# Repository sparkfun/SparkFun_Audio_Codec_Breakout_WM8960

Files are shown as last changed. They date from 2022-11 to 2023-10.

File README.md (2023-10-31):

Stereo Audio Codec Breakout - WM8960
========================================

<table class="table table-hover table-striped table-bordered">
  <tr align="center">
   <td><a href="https://www.sparkfun.com/products/21250">SparkFun Audio Codec Breakout - WM8960</a></td>
   <td><a href="https://www.sparkfun.com/products/21772">SparkFun Audio Codec Breakout - WM8960 with Headers (Qwiic)</a></td>
  </tr>
  <tr align="center">
   <td><i>SparkFun Audio Codec Breakout - WM8960<br />[<a href="https://www.sparkfun.com/products/21250">BOB-21250</a>]</i></td>
   <td><i>SparkFun Audio Codec Breakout - WM8960 with Headers (Qwiic)<br />[<a href="https://www.sparkfun.com/products/21772">BOB-21772</a>]</i></td>
  </tr>
</table>

The SparkFun WM8960 Audio Codec Breakout is a low-power, high-quality stereo codec with 1W Stereo Class D speaker drivers and headphone drivers. The WM8960 acts as a stereo audio ADC and DAC and communicates using I<sup>2</sup>S, a standard audio data protocol (not to be confused with I<sup>2</sup>C). This audio codec is chock full of features some of which include advanced on-chip digital signal processing for automatic level control (ALC) for the line or microphone input, programmable gain amplifier (PGA), pop and click suppression, and its ability to configure I<sup>2</sup>S settings and analog audio path through software via I<sup>2</sup>C. 

The 6x flexible analog input pins allow for a variety of sound source signal types to be routed internally to the ADC inputs. These signal types include line level and microphone level (balanced, and un-balanced) sources. This allows you to accept audio from the sound card on your computer, headphone output of your smartphone, electret microphones, MEMs microphone, etc. The flexible analog signal routing includes PGAs and multiple boost stages so that it can accept a wide range of audio signal levels.

Its efficient class-D driver also means low heat and long battery life when driving 8&ohm; speakers at up to 1W per channel for portable audio applications. As an alternative output, users can also use the audio codec to drive 16&ohm; headphones at up to 40mW for portable audio applications.

Audio feeling a bit... empty? Turn on the 3D enhancement to artificially increase the separation between the left and right channels. In other words, you will feel as if the room is full of sound coming from all directions during playback.  We've written an extensive Arduino Library that allows you to easily control all of the audio codec's features from simple volume control to 3D-enhanced audio playback. 

The board breaks out the WM8960 pins along the edge of the PCB with 0.1"-spaced pins to connect to a breadboard. Utilizing our handy Qwiic system saves you from manually wiring the I<sup>2</sup>C port when configuring the audio codec's settings. A power LED (PWR) is included on the board to indicate when power is applied to the audio CODEC through 3.3V. It can be disabled by cutting the LED jumper on the bottom side. To power the analog (AVDD) and speaker driver (SPKVDD), you will need to include power on the VIN pin. The built-in XC6222 3.3V/700mA voltage regulator regulates the voltage down for the analog circuit. Jumpers for the analog circuit (i..e. AVDD-ISO) and speaker drivers (VIN/SPKVDD) are included for users that want to power each with a separate power supply. 

This board is great for projects that require you to encode or decode audio signals. Add the SparkFun Audio Codec Breakout WM8960 to your next portable digital player or immersive VR game. 

Repository Contents
-------------------

* **/Documents** - Datasheets, additional product information
* **/Hardware** - Eagle design files (.brd, .sch)

Documentation
--------------

* **[Library](https://github.com/sparkfun/SparkFun_WM8960_Arduino_Library)** - Arduino library for the Stereo Audio Codec Breakout - WM8960.
* **[SparkFun Fritzing Part](https://github.com/sparkfun/Fritzing_Parts/blob/main/products/21250_sfe_stereo_audio_codec_breakout_WM8960.fzpz)** - Fritzing diagrams for SparkFun products.
* **[Hookup Guide](https://learn.sparkfun.com/tutorials/2761)** - Basic hookup guide for the Stereo Audio Codec Breakout - WM8960.

Product Versions
----------------

* [BOB-21772](https://www.sparkfun.com/products/21772) - v1.0, with headers
* [BOB-21250](https://www.sparkfun.com/products/21250) - Initial Release, v1.0 

Version History
---------------
* v1.0 - Initial Release 

License Information
-------------------

This product is _**open source**_! 

Please review the LICENSE.md file for license information. 

If you have any questions or concerns on licensing, please contact technical support on our [SparkFun forums](https://forum.sparkfun.com/viewforum.php?f=152).

Distributed as-is; no warranty is given.

- Your friends at SparkFun.

_<COLLABORATION CREDIT>_

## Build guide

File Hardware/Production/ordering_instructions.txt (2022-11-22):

panel size, 91x178mm
PCB thickness, 1.6mm
number of layers, 4
soldermask color, Red
silkscreen color, White
oz copper, 1oz
finish, HASL lead free
stencils, top
pcs per panel, 12
min trace width, 0.2032mm / 0.0080in
min drill size, 0.3810mm / 0.0150in
filename to layer stackup 1/2/3/4: GTL, GL2, GL3, GBL

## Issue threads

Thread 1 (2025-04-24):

[Question] Accessing MICBIAS on WM8960 and Raspberry PI

AustinMutschler, 2025-04-24:
## Background

I have a question that is not directly about this audio hat but uses the same WM8960 audio chip and was wondering if any of you folks could point me in the right direction (I know this is not the best place but I don't know who else to ask). I'm using the [SparkFun Audio Codec Breakout - WM8960](https://learn.sparkfun.com/tutorials/audio-codec-breakout---wm8960-hookup-guide/all#introduction).

I have been searching everywhere online to make this board work with the PI as it is usually used with arduinos but I get stuck at powering the electret mic with micbias.

Currently the Waveshare WM8960 soundcard overlay is the only one I have found for this audio chip. I am not entirely sure if it is the MICBIAS control that is not working but after all the troubleshooting, it is the consistent thing that keeps coming back up as it never reads any voltage while recording. Speakers work great by the way.

## The Project

<details>
 <summary>Full Wiring Diagram</summary>

**Power**
Pi 3.3V (Physical Pin 1 or 17) -> WM8960 3V3
Pi 5V (Physical Pin 2 or 4) -> WM8960 VIN
Pi Ground (Any GND Pin, e.g., Pin 6) -> WM8960 GND

**I2C**
Pi SDA (GPIO 2, Physical Pin 3) -> WM8960 SDA
Pi SCL (GPIO 3, Physical Pin 5) -> WM8960 SCL

**I2S**
Pi BCLK (Bit Clock) (GPIO 18, Physical Pin 12) -> WM8960 BCLK
Pi LRC / WS (Left/Right Clock / Word Select) (GPIO 19, Physical Pin 35) -> WM8960 DACLRC (also referred to as DLRC on top silkscreen) - The datasheet notes this often serves as the frame clock for both ADC and DAC when the ADC is enabled.
Pi DOUT (Data Out from Pi / Data In to Codec) (GPIO 21, Physical Pin 40) -> WM8960 DACDAT (also referred to as DDAT on top silkscreen)
Pi DIN (Data In to Pi / Data Out from Codec) (GPIO 20, Physical Pin 38) -> WM8960 ADCDAT (also referred to as ADAT on top silkscreen)

**MIC**
MICBIAS -> 2.2kohm resistor -> LINPUT2
MIC+ -> LINPUT2
MIC- -> LINPUT1
LINPUT1 -> JUMPER -> GND

</details>

I am attempting to connect this board to a Raspberry PI 4. It currently runs the latest version of Raspberry PI OS and by default the wb8960-soundcard overlay is [this one](https://github.com/raspberrypi/linux/blob/rpi-6.12.y/arch/arm/boot/dts/overlays/wm8960-soundcard-overlay.dts).

I am connecting an analog speaker and what I believe is a Electret Microphone from this [ATT 210 phone](https://a.co/d/7MxzDRN). The basic idea is, I am taking over the phone's matrix keypad with the PI and it's audio, not using any of the board in the phone whatsoever besides the matrix keypad. I have already setup the keypad matrix to the PI GPIO but then I needed audio. This phone is small so I cannot use a hat for the project. In fact, I purchased this audio hat first. The second issue I had was I wanted to use the original phone microphone because it will likely be better than a MEMS mic sitting in the housing. I found that the SparkFun WM8960 Board checked all the boxes as it supports external electret mics.

I setup the speaker and it worked after turning on the "Left Out Mixer PCM" setting.

Then I turned to the microphone...

## The Mic Setup

I set the microphone up in a [differential configuration](https://learn.sparkfun.com/tutorials/audio-codec-breakout---wm8960-hookup-guide/all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,Differential%20Microphone%20Input,-The%20following%20connection). This means I connected it in the following way:

MICBIAS -> 2.2kohm resistor -> LINPUT2
MIC+ -> LINPUT2
MIC- -> LINPUT1
LINPUT1 -> JUMPER -> GND

Previously I did try to do a standard mic setup but it yielded the same results:
MICBIAS -> 2.2kohm resistor -> LINPUT1
MIC+ -> LINPUT1
MIC- -> GND

The Card is 3 so for code examples below I have listed 3,0 which is targeting the WM8960.

<details>
 <summary>Full alsamixer Settings</summary>

```text
headphone - off (I have tried this setting on and off)
headphone playback zc - off
speaker - db gain: -17 -17
speaker ac - 0
speaker dc - 0
speaker playback zc - off
PCM Playback - 00 (enabled)
Mono Output Mixer Left - off
Mono Output Mixer Right - off
Playback - DB -20 -20
capture volume zc - off - (NOTE: I have had this off and on and neither make a difference)
3d - mute
3d filter lower cut-off - low
3d filter upper cut-off - high
ADC data - left data = left adc; right data = right adc
ADC high pass filter - off
ADC polarity - no inversion
ALC attack - 13
ALC Decay - 20
ALC Function - off
ALC Hold time - 0
ALC Max Gain - 100
ALC Min Gain - 0
ALC Mode - ALC
DAC Deemphasis - off
DAC Filter Characteristics - Normal
DAC Mono Mix - mono
DAC Polarity - No Inversion
Left Boost Mixer LINPUT1 - 00 (Enabled)
Left Boost Mixer LINPUT2 - Off (I have )
Left Boost Mixer LINPUT3- Off
Left Input Boost Mixer LINPUT1 - DB Gain 29 - 100%
Left Input Boost Mixer LINPUT2 - DB Gain 29 - 100%
Left Input Boost Mixer LINPUT3 - DB Gain mute - 0%
Left Input Mixer Boost - 00 (ENABLED)
Left Output Mixer Boost Bypass - db gain -15
Left Output Mixer LINPUT3 - db gain -15
Left Out Mixer PCM - 00 (ENABLED)
Noise Gate - off
Noise Gate Threshold - 0
Right Boost Mixer RINPUT1 - off
Right Boost Mixer RINPUT2 - off
Right Boost Mixer RINPUT3 - off
Right Input Boost Mixer RINPUT1 - DB Gain - 0%
Right Input Boost Mixer RINPUT2 - DB Gain mute - 0%
Right Input Boost Mixer RINPUT3 - DB Gain mute - 0%
Right Input Mixer Boost - off
Right Output Mixer Boost Bypass - DB Gain -15
Right Output Mixer PCM - off
Right Output Mixer RINPUT3 - DB Gain -15
```

</details>

<details>
 <summary>/boot/firmware/config.txt</summary>

```text
# For more options and information see
# http://rptl.io/configtxt
# Some settings may impact device functionality. See link above for details
dtdebug=1
# Uncomment some or all of these to enable the optional hardware interfaces
dtparam=i2c_arm=on
dtparam=i2s=on
#dtparam=spi=on

# Enable audio (loads snd_bcm2835)
dtparam=audio=on

# Additional overlays and parameters are documented
# /boot/firmware/overlays/README

# Automatically load overlays for detected cameras
camera_auto_detect=1

# Automatically load overlays for detected DSI displays
display_auto_detect=1

# Automatically load initramfs files, if found
auto_initramfs=1

# Enable DRM VC4 V3D driver
dtoverlay=vc4-kms-v3d
max_framebuffers=2

# Don't have the firmware create an initial video= setting in cmdline.txt.
# Use the kernel's default instead.
disable_fw_kms_setup=1

# Run in 64-bit mode
arm_64bit=1

# Disable compensation for displays with overscan
disable_overscan=1

# Run as fast as firmware / board allows
arm_boost=1

[cm4]
# Enable host mode on the 2711 built-in XHCI USB controller.
# This line should be removed if the legacy DWC2 controller is required
# (e.g. for USB device mode) or if USB support is not required.
otg_mode=1

[cm5]
dtoverlay=dwc2,dr_mode=host

[all]
dtoverlay=wm8960-soundcard
```

</details>

## The Problem

When trying to record audio, the audio file is completely silent. I have used the following commands to record and then test the file.

Note: I have also attempted to listen to the file and it is silent. I have also attempted to pipe the recording into the speaker and can confirm, I hear nothing.

```sh
arecord -D plughw:3,0 -f S16_LE -r 44100 -c 1 -d 10 test-mic.wav
sox test-mic.wav -n stat
```

Levels Remain at 0
```sh
arecord -D plughw:3,0 -f S16_LE -r 44100 -c1 -V mono /dev/null
```

### Suspected Issue

After a lot of trial and error, I believe the issue boils down to the MICBIAS **not** supplying voltage to the microphone. I have tested with my multimeter and it never seems to activate while recording on the device. I am not sure **why** voltage is not being supplied when recording, whether it is a setting I missed or if it is because the dtoverlay does not set MICBIAS

When running `dmesg | grep -i wm8960` I get the following messages

```sh
[    7.450473] wm8960 1-001a: supply DCVDD not found, using dummy regulator
[    7.450704] wm8960 1-001a: supply DBVDD not found, using dummy regulator
[    7.450891] wm8960 1-001a: supply SPKVDD1 not found, using dummy regulator
[    7.450949] wm8960 1-001a: supply SPKVDD2 not found, using dummy regulator
```

I am not sure if this is relevant or not to my issue.

### What Have I Tried

I have tried changing the audio capture controls around a lot and none seem to make the MIC work. I began looking into the [built in dtoverlay](https://github.com/raspberrypi/linux/blob/rpi-6.12.y/arch/arm/boot/dts/overlays/wm8960-soundcard-overlay.dts). I don't know much about overlays but noticed the official one bundled with the OS is for this this audio hat specifically and may hold the key to my issue.

I attempted to modify the dtoverlay to add some things that I might need. Granted, my knowledge is extremely limited with this and likely not correct. Here are the changes I made.

Within fragment@2 I added `micbias-supply` and `micbias-resistor` like so:

```text
fragment@2 {
		target = <&i2c1>;
		__overlay__ {
			#address-cells = <1>;
			#size-cells = <0>;
			status = "okay";

			wm8960: wm8960@1a {
				compatible = "wlf,wm8960";
				reg = <0x1a>;
				#sound-dai-cells = <0>;
				AVDD-supply = <&vdd_5v0_reg>;
				DVDD-supply = <&vdd_3v3_reg>;
				clocks = <&wm8960_mclk>;
				clock-names = "mclk";
				micbias-supply   = <&vdd_3v3_reg>;
				micbias-resistor = <2200>;
			};
		};
	};
```

Within fragment@3 I added the LINPUT2 to the simple-audio-card,routing section like so:

``` text
simple-audio-card,routing =
  "Headphone Jack", "HP_L",
  "Headphone Jack", "HP_R",
  "Speaker", "SPK_LP",
  "Speaker", "SPK_LN",
  "LINPUT1", "Mic Jack",
  "LINPUT2", "Mic Jack",
  "LINPUT3", "Mic Jack",
  "RINPUT1", "Mic Jack",
  "RINPUT2", "Mic Jack";
```

For compiling I used the following commands for all of my attempts

```shell
sudo dtc -@ -I dts -O dtb -o wm8960-soundcard-bias.dtbo wm8960-soundcard-bias-overlay.dts
sudo cp wm8960-soundcard-bias.dtbo /boot/firmware/overlays/
```
Then updated the config.txt file to match the correct name of the new dtoverlay `dtoverlay=wm8960-soundcard-bias` and rebooted.

To test that the audio card actually applied these settings to the device tree I ran the following commands:

```shell
sudo dtc -I fs -O dts /proc/device-tree > /tmp/flat.dts
grep -R "micbias" -n /tmp/flat.dts
```

Which yielded this result

```shell
253:				micbias-resistor = <0x898>;
261:				micbias-supply = <0xef>;
```

## Conclusion

I have tried rewiring the audio a few times to ensure it wasn't an issue with the wiring. I have checked that nothing is shorted on the hardware side and I2C is communicating. I have check voltages and everything is good except the MICBIAS pin. The speakers work.

I am not sure where to go from here. I assume that this audio hat does not require MICBIAS because of the built in MEMS microphone and therefore the controls are not in the dtoverlay. I do not know enough about dtoverlays to make the necessary modifications to port to the SparkFun WM8960 Breakout Board.

If anyone could point me in the right direction I would truly appreciate it.

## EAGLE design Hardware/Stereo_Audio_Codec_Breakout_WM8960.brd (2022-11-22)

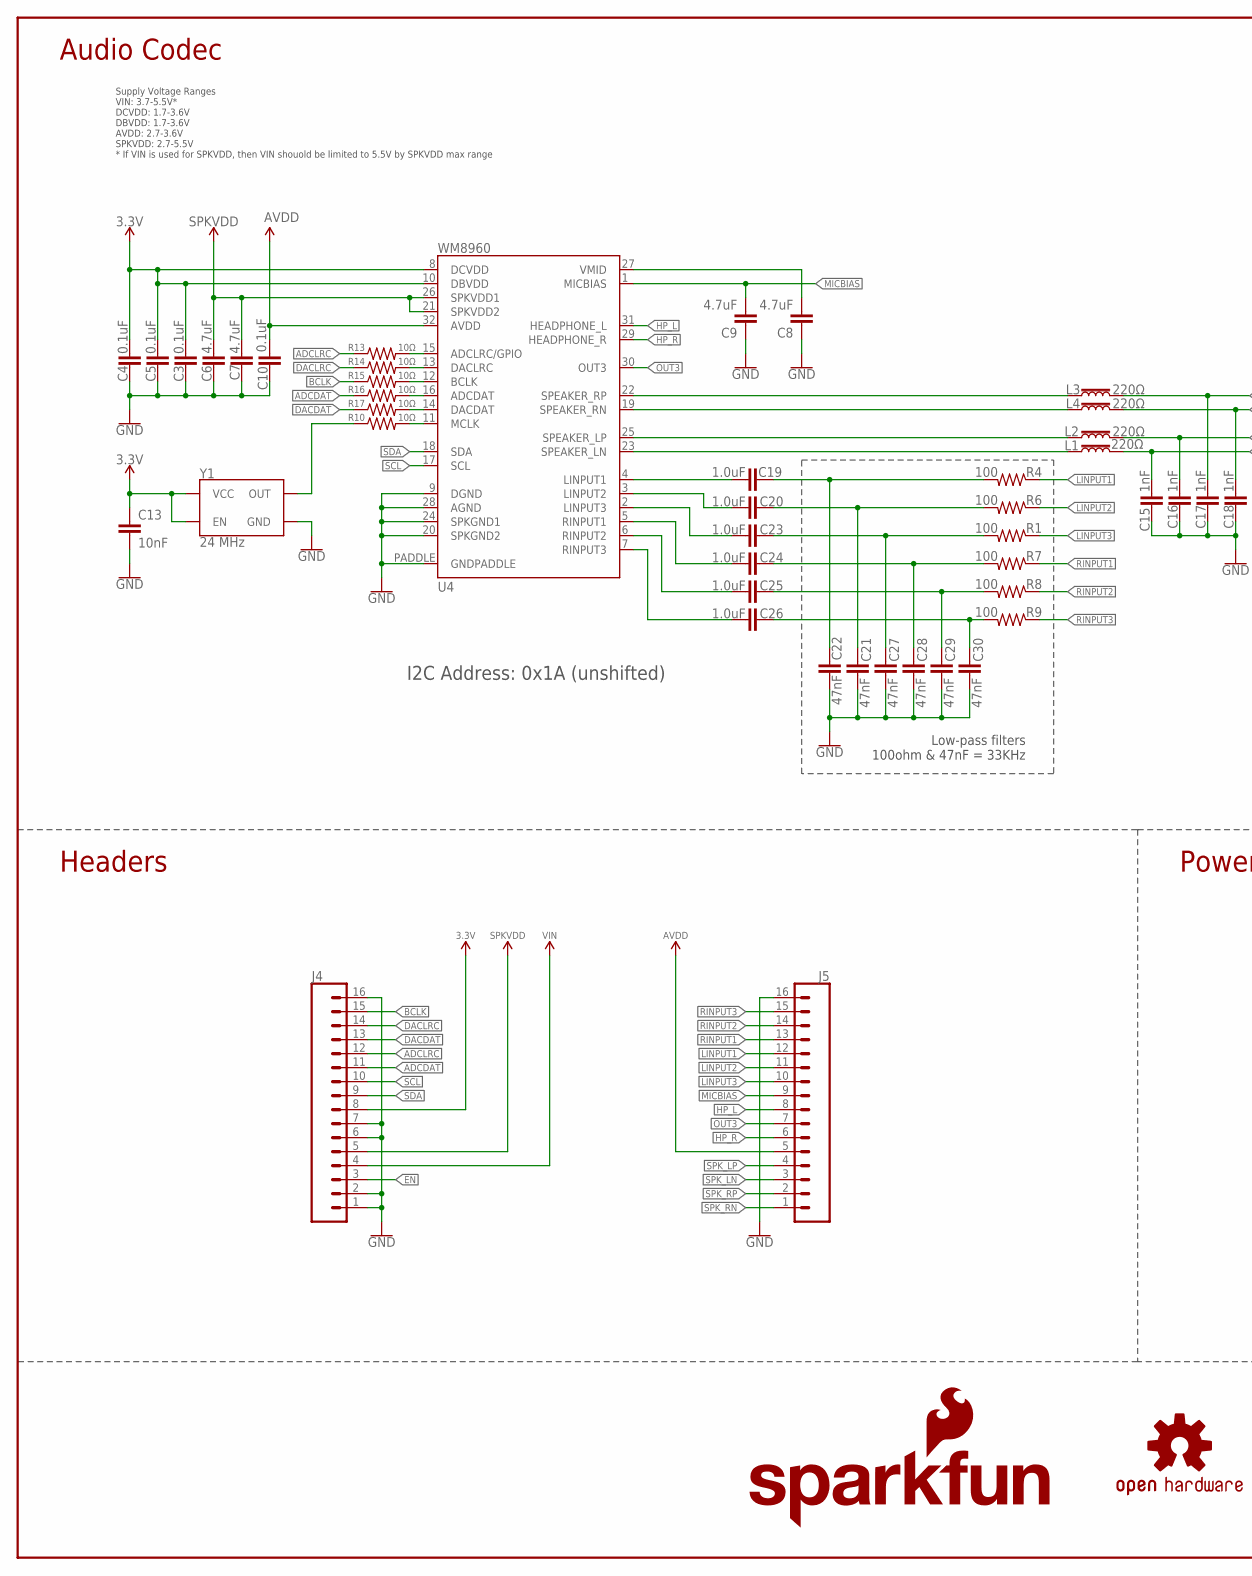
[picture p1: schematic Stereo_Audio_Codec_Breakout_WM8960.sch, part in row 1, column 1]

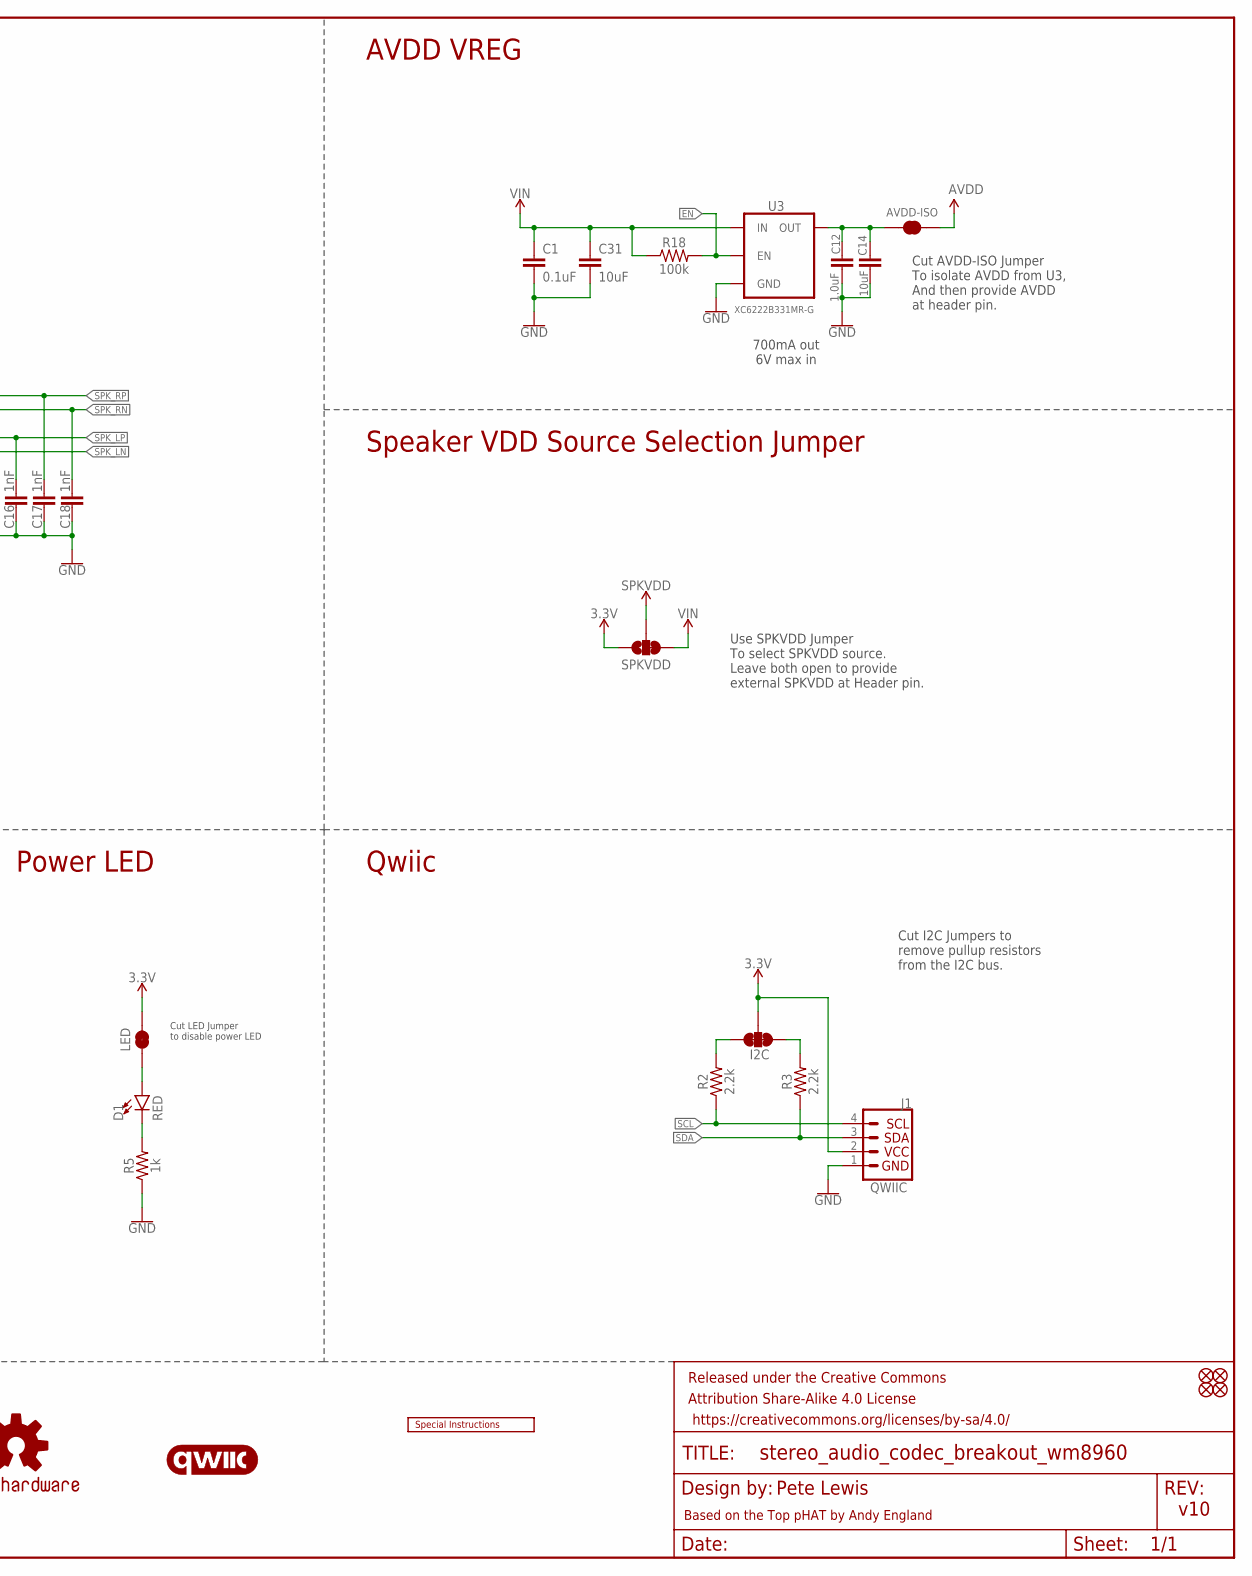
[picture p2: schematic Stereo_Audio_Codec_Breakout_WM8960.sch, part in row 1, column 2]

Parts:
AVDD-ISO: JUMPER-SMT_2_NC_TRACE_SILK; SMT-JUMPER_2_NC_TRACE_SILK
C1, C3, C4, C5, C10: 0.1uF; 0402-TIGHT
C6, C7: 4.7uF; 0603
C8, C9: 4.7uF; 0402-TIGHT
C12, C19, C20, C23, C24, C25, C26: 1.0uF; 0402-TIGHT
C13: 10nF; 0402-TIGHT
C14, C31: 10uF; 0402-TIGHT
C15, C16, C17, C18: 1nF; 0402
C21, C22, C27, C28, C29, C30: 47nF; 0402-TIGHT
D1: RED; LED-0603
FD1, FD2, FD3, FD4: FIDUCIALUFIDUCIAL; FIDUCIAL-MICRO
FRAME1: FRAME-LEDGER; CREATIVE_COMMONS
I2C: JUMPER-SMT_3_2-NC_TRACE_SILK; SMT-JUMPER_3_2-NC_TRACE_SILK
J1: QWIIC; JST04_1MM_RA
J4, J5: CONN_161X16_NO_SILK; 1X16_NO_SILK
L1, L2, L3, L4: 220Ω; 0805
LED: JUMPER-SMT_2_NC_TRACE_SILK; SMT-JUMPER_2_NC_TRACE_SILK
LOGO1: SFE_LOGO_NAME_FLAME.1_INCH; SFE_LOGO_NAME_FLAME_.1
LOGO3: QWIIC_LOGO_4MM; QWIIC_4MM
LOGO4: OSHW-LOGOS; OSHW-LOGO-S
LOGO5: SPECIAL_INSTRUCTIONS-ORDERING; ORDERING_INSTRUCTIONS
R1, R4, R6, R7, R8, R9: 100; 0402-TIGHT
R2, R3: 2.2k; 0402-TIGHT
R5: 1k; 0402-TIGHT
R10, R13, R14, R15, R16, R17: 10Ω; 0402-TIGHT
R18: 100k; 0402-TIGHT
SPKVDD: JUMPER-SMT_3_1-NC_TRACE_SILK; SMT-JUMPER_3_1-NC_TRACE_SILK
U3: XC6222B331MR-G; SOT23-5
U4: WM8960; QFN-32
Y1: 24 MHz; RESONATOR-SMD-3.2X2.5

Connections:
3.3V: C3.2, C4.2, C5.2, C13.1, I2C.2, J1.2, J4.8, LED.2, SPKVDD.1, U4.8 (DCVDD), U4.10 (DBVDD), Y1.1 (EN), Y1.4 (VCC)
ADCDAT: J4.11, R16.1
ADCLRC: J4.12, R13.1
AVDD: AVDD-ISO.2, C10.2, J5.5, U4.32 (AVDD)
AVDD-REG: AVDD-ISO.1, C12.1, C14.1, U3.5 (OUT)
BCLK: J4.15, R15.1
DACDAT: J4.13, R17.1
DACLRC: J4.14, R14.1
EN: J4.3, R18.2, U3.3 (EN)
GND: C1.2, C3.1, C4.1, C5.1, C6.2, C7.2, C8.1, C9.1, C10.1, C12.2, C13.2, C14.2, C15.2, C16.2, C17.2, C18.2, C21.2, C22.2, C27.2, C28.2, C29.2, C30.2, C31.2, J1.1, J4.1, J4.2, J4.6, J4.7, J4.16, J5.16, R5.1, U3.2 (GND), U4.9 (DGND), U4.20 (SPKGND2), U4.24 (SPKGND1), U4.28 (AGND), U4.PADDLE (GNDPADDLE), Y1.2 (GND)
HP_L: J5.8, U4.31 (HEADPHONE_L)
HP_R: J5.6, U4.29 (HEADPHONE_R)
LINPUT1: J5.12, R4.1
LINPUT2: J5.11, R6.1
LINPUT3: J5.10, R1.1
MICBIAS: C9.2, J5.9, U4.1 (MICBIAS)
unnamed: L3.1, U4.22 (SPEAKER_RP)
unnamed: R13.2, U4.15 (ADCLRC/GPIO)
unnamed: L4.1, U4.19 (SPEAKER_RN)
unnamed: L2.1, U4.25 (SPEAKER_LP)
unnamed: L1.1, U4.23 (SPEAKER_LN)
unnamed: D1.C, R5.2
unnamed: D1.A, LED.1
unnamed: C26.2, U4.7 (RINPUT3)
unnamed: C25.2, U4.6 (RINPUT2)
unnamed: C23.2, U4.2 (LINPUT3)
unnamed: R10.1, Y1.3 (OUT)
unnamed: C20.2, U4.3 (LINPUT2)
unnamed: C20.1, C21.1, R6.2
unnamed: C19.1, C22.1, R4.2
unnamed: C23.1, C27.1, R1.2
unnamed: I2C.3, R2.2
unnamed: I2C.1, R3.2
unnamed: C24.1, C28.1, R7.2
unnamed: C25.1, C29.1, R8.2
unnamed: C26.1, C30.1, R9.2
unnamed: R14.2, U4.13 (DACLRC)
unnamed: R15.2, U4.12 (BCLK)
unnamed: R16.2, U4.16 (ADCDAT)
unnamed: R17.2, U4.14 (DACDAT)
unnamed: R10.2, U4.11 (MCLK)
unnamed: C19.2, U4.4 (LINPUT1)
unnamed: C24.2, U4.5 (RINPUT1)
unnamed: C8.2, U4.27 (VMID)
OUT3: J5.7, U4.30 (OUT3)
RINPUT1: J5.13, R7.1
RINPUT2: J5.14, R8.1
RINPUT3: J5.15, R9.1
SCL: J1.4, J4.10, R2.1, U4.17 (SCL)
SDA: J1.3, J4.9, R3.1, U4.18 (SDA)
SPKVDD: C6.1, C7.1, J4.5, SPKVDD.2, U4.21 (SPKVDD2), U4.26 (SPKVDD1)
SPK_LN: C15.1, J5.3, L1.2
SPK_LP: C16.1, J5.4, L2.2
SPK_RN: C18.1, J5.1, L4.2
SPK_RP: C17.1, J5.2, L3.2
VIN: C1.1, C31.1, J4.4, R18.1, SPKVDD.3, U3.1 (IN)

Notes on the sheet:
Pete Lewis
Audio Codec
Cut I2C Jumpers to remove pullup resistors from the I2C bus.
v10
Based on the Top pHAT by Andy England
I2C Address: 0x1A (unshifted)
Cut LED Jumper to disable power LED
Low-pass filters 100ohm & 47nF = 33KHz
Supply Voltage Ranges VIN: 3.7-5.5V* DCVDD: 1.7-3.6V DBVDD: 1.7-3.6V AVDD: 2.7-3.6V SPKVDD: 2.7-5.5V * If VIN is used for SPKVDD, then VIN shouold be limited to 5.5V by SPKVDD max range
AVDD VREG
Headers
Qwiic
Speaker VDD Source Selection Jumper
700mA out 6V max in
Cut AVDD-ISO Jumper To isolate AVDD from U3, And then provide AVDD at header pin.
Use SPKVDD Jumper To select SPKVDD source. Leave both open to provide external SPKVDD at Header pin.
Power LED

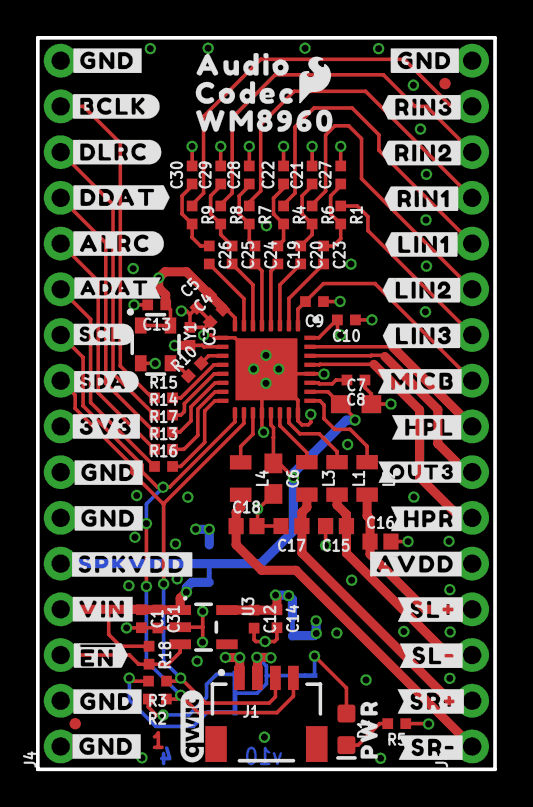
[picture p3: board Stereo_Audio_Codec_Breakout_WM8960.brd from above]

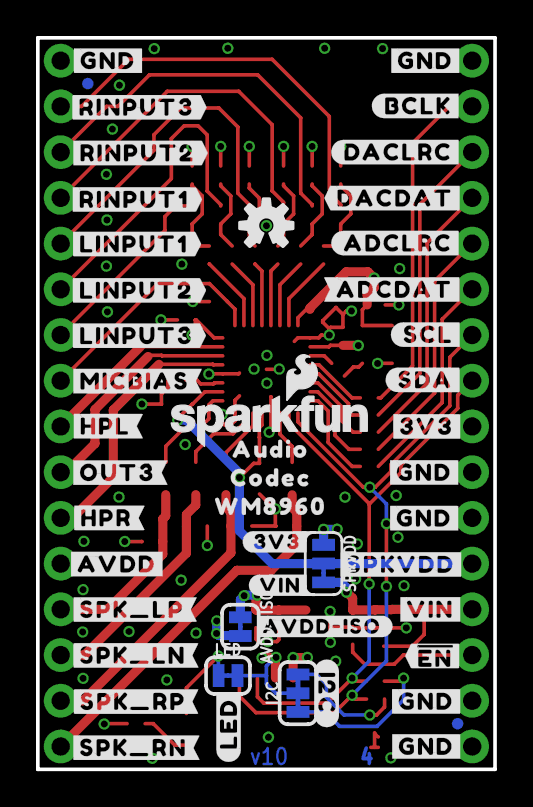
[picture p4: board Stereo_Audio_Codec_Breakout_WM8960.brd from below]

Board: 4 copper layers, 25.4 x 40.6 mm, 146 parts (48 on the bottom side), 56 nets.

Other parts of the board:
U$1: AUDIO8960896055
U$2: CODEC8960896056
U$3: CODEC8960896057
U$4, U$7, U$8, U$9, U$11, U$12, U$17, U$18, U$19, U$31, U$32, U$50: #GND#8
U$5: #BCLK#0
U$10, U$48: #AVDD#22
U$13: #SR##4
U$14: #SL##6
U$15: #SR##5
U$16: #SL##7
U$20: #AVDD#ISO#0
U$21: #3V3#0
U$22: #VIN#0
U$23: #ALRC#0
U$24: #DLRC#1
U$26: #HPL#10
U$27: #HPR#11
U$28, U$51: #3V3#12
U$29: SFE_LOGO_FLAME_.1
U$30, U$64: #SPKVDD#51
U$34: ##EN##1
U$35: PWR12
U$36: WM8960896054
U$37: #OUT3#0
U$38: ##EN##2
U$39: #LED#17
U$40: #I2C#18
U$41: #OUT3#4
U$44: #RINPUT1#0
U$45, U$46: #VIN#19
U$47: #RINPUT2#0
U$49: #RINPUT3#0
U$52: #ADCLRC#2
U$54: #RIN3#0
U$55: #DACLRC#4
U$56: #RIN2#0
U$57: #BCLK#5
U$58: #ADCDAT#6
U$59: #MICB#31
U$60: WM89600
U$61: AUDIO0
U$62: #LINPUT1#0
U$63: #LINPUT2#0
U$65: #LINPUT3#0
U$66: #SCL#0
U$67: #SDA#0
U$68: #RIN1#0
U$69: #DDAT#9
U$70: #DACDAT#8
U$71: #ADAT#10
U$74: #SCL#40
U$75: #SDA#41
U$76: #LIN1#0
U$77: #LIN2#0
U$78: #LIN3#0
U$79: #MICBIAS#42
U$80: #HPL#43
U$82: #HPR#45
U$83: #SPK_LP#46
U$84: #SPK_LN#47
U$85: #SPK_RP#48
U$86: #SPK_RN#49

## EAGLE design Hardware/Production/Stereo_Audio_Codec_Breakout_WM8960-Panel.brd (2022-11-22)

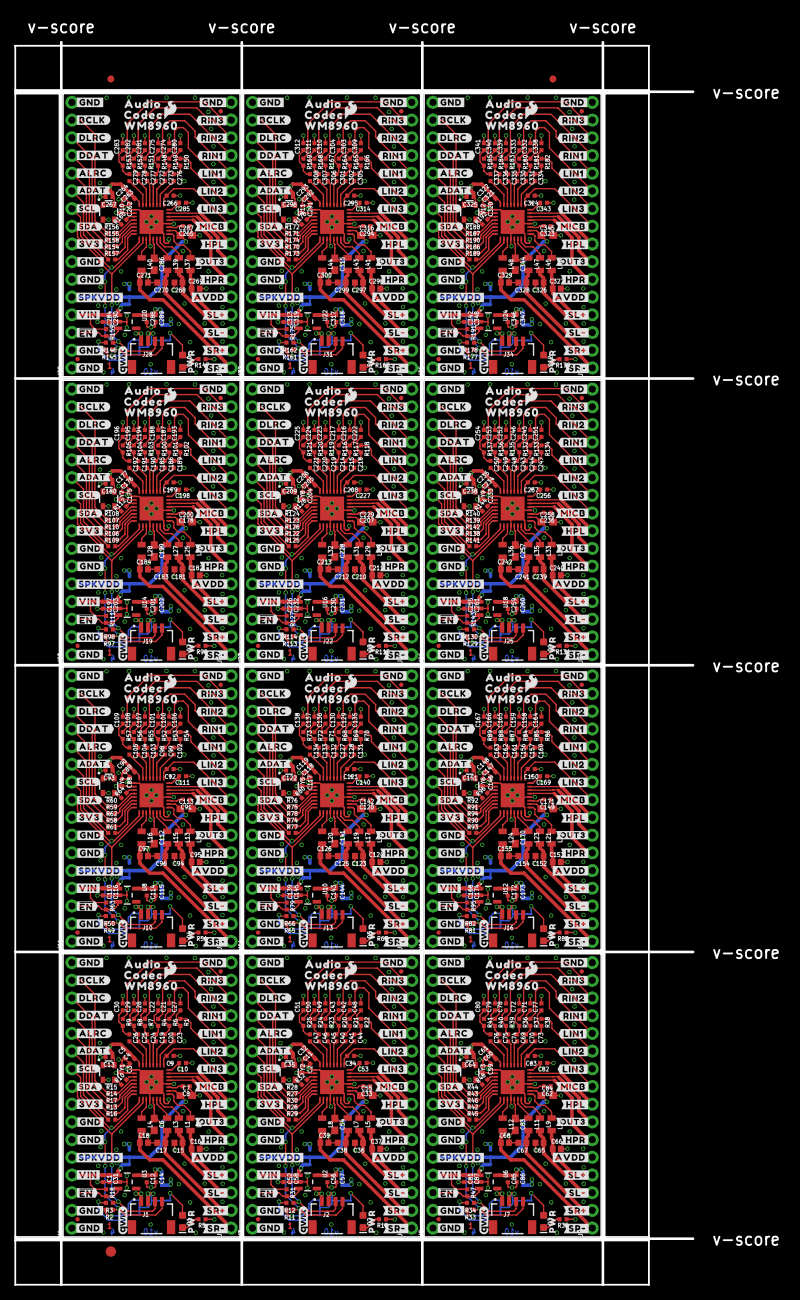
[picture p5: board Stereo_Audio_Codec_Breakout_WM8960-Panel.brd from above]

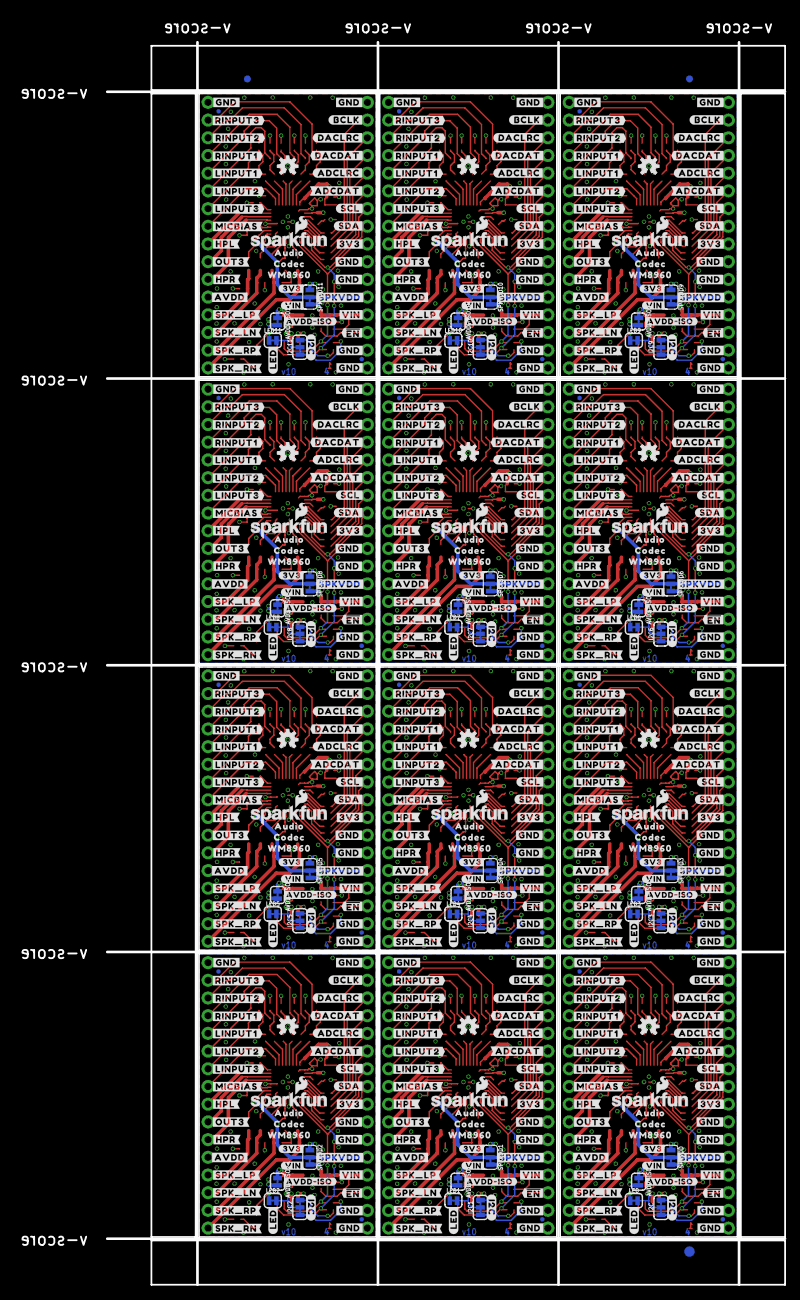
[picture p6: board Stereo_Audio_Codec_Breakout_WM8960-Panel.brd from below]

Board: 4 copper layers, 97.3 x 178.3 mm, 1734 parts (579 on the bottom side), 672 nets.

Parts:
AVDD-ISO, AVDD-ISO1, AVDD-ISO2, AVDD-ISO3, AVDD-ISO4, AVDD-ISO5, AVDD-ISO6, AVDD-ISO7, AVDD-ISO8, AVDD-ISO9, AVDD-ISO10, AVDD-ISO11: SMT-JUMPER_2_NC_TRACE_SILK
C1, C2, C3, C4, C5, C10, C11, C32, C52, C53, C59, C60, C61, C81, C82, C88, C89, C90, C110, C111, C117, C118, C119, C139, C140, C146, C147, C148, C168, C169, C175, C176, C177, C197, C198, C204, C205, C206, C226, C227, C233, C234, C235, C255, C256, C262, C263, C264, C284, C285, C291, C292, C293, C313, C314, C320, C321, C322, C342, C343: 0.1uF; 0402-TIGHT
C6, C7, C54, C55, C83, C84, C112, C113, C141, C142, C170, C171, C199, C200, C228, C229, C257, C258, C286, C287, C315, C316, C344, C345: 4.7uF; 0603
C8, C9, C33, C34, C62, C63, C91, C92, C120, C121, C149, C150, C178, C179, C207, C208, C236, C237, C265, C266, C294, C295, C323, C324: 4.7uF; 0402-TIGHT
C12, C19, C20, C23, C24, C25, C26, C40, C41, C44, C45, C46, C47, C56, C69, C70, C73, C74, C75, C76, C85, C98, C99, C102, C103, C104, C105, C114, C127, C128, C131, C132, C133, C134, C143, C156, C157, C160, C161, C162, C163, C172, C185, C186, C189, C190, C191, C192, C201, C214, C215, C218, C219, C220, C221, C230, C243, C244, C247, C248, C249, C250, C259, C272, C273, C276, C277, C278, C279, C288, C301, C302, C305, C306, C307, C308, C317, C330, C331, C334, C335, C336, C337, C346: 1.0uF; 0402-TIGHT
C13, C35, C64, C93, C122, C151, C180, C209, C238, C267, C296, C325: 10nF; 0402-TIGHT
C14, C31, C57, C58, C86, C87, C115, C116, C144, C145, C173, C174, C202, C203, C231, C232, C260, C261, C289, C290, C318, C319, C347, C348: 10uF; 0402-TIGHT
C15, C16, C17, C18, C36, C37, C38, C39, C65, C66, C67, C68, C94, C95, C96, C97, C123, C124, C125, C126, C152, C153, C154, C155, C181, C182, C183, C184, C210, C211, C212, C213, C239, C240, C241, C242, C268, C269, C270, C271, C297, C298, C299, C300, C326, C327, C328, C329: 1nF; 0402
C21, C22, C27, C28, C29, C30, C42, C43, C48, C49, C50, C51, C71, C72, C77, C78, C79, C80, C100, C101, C106, C107, C108, C109, C129, C130, C135, C136, C137, C138, C158, C159, C164, C165, C166, C167, C187, C188, C193, C194, C195, C196, C216, C217, C222, C223, C224, C225, C245, C246, C251, C252, C253, C254, C274, C275, C280, C281, C282, C283, C303, C304, C309, C310, C311, C312, C332, C333, C338, C339, C340, C341: 47nF; 0402-TIGHT
D1, D2, D3, D4, D5, D6, D7, D8, D9, D10, D11, D12: RED; LED-0603
E$1, E$2, E$3, E$4: FIDUCIAL-1X2
E$5, E$6: FIDUCIAL-1.5X3
FD1, FD2, FD3, FD4, FD5, FD6, FD7, FD8, FD9, FD10, FD11, FD12, FD13, FD14, FD15, FD16, FD17, FD18, FD19, FD20, FD21, FD22, FD23, FD24, FD25, FD26, FD27, FD28, FD29, FD30, FD31, FD32, FD33, FD34, FD35, FD36, FD37, FD38, FD39, FD40, FD41, FD42, FD43, FD44, FD45, FD46, FD47, FD48: FIDUCIALUFIDUCIAL; FIDUCIAL-MICRO
I2C, I2C1, I2C2, I2C3, I2C4, I2C5, I2C6, I2C7, I2C8, I2C9, I2C10, I2C11: JUMPER-SMT_3_2-NC_TRACE_SILK; SMT-JUMPER_3_2-NC_TRACE_SILK
J1, J2, J7, J10, J13, J16, J19, J22, J25, J28, J31, J34: QWIIC; JST04_1MM_RA
J3, J4, J5, J6, J8, J9, J11, J12, J14, J15, J17, J18, J20, J21, J23, J24, J26, J27, J29, J30, J32, J33, J35, J36: 1X16_NO_SILK
L1, L2, L3, L4, L5, L6, L7, L8, L9, L10, L11, L12, L13, L14, L15, L16, L17, L18, L19, L20, L21, L22, L23, L24, L25, L26, L27, L28, L29, L30, L31, L32, L33, L34, L35, L36, L37, L38, L39, L40, L41, L42, L43, L44, L45, L46, L47, L48: 220Ω; 0805
LED, LED1, LED2, LED3, LED4, LED5, LED6, LED7, LED8, LED9, LED10, LED11: SMT-JUMPER_2_NC_TRACE_SILK
LOGO1, LOGO6, LOGO9, LOGO12, LOGO15, LOGO18, LOGO21, LOGO24, LOGO27, LOGO30, LOGO33, LOGO36: SFE_LOGO_NAME_FLAME.1_INCH; SFE_LOGO_NAME_FLAME_.1
LOGO2, LOGO3, LOGO7, LOGO10, LOGO13, LOGO16, LOGO19, LOGO22, LOGO25, LOGO28, LOGO31, LOGO34: QWIIC_LOGO_4MM; QWIIC_4MM
LOGO4, LOGO5, LOGO8, LOGO11, LOGO14, LOGO17, LOGO20, LOGO23, LOGO26, LOGO29, LOGO32, LOGO35: OSHW-LOGOS; OSHW-LOGO-S
R1, R4, R6, R7, R8, R9, R20, R21, R22, R23, R24, R25, R36, R37, R38, R39, R40, R41, R52, R53, R54, R55, R56, R57, R68, R69, R70, R71, R72, R73, R84, R85, R86, R87, R88, R89, R100, R101, R102, R103, R104, R105, R116, R117, R118, R119, R120, R121, R132, R133, R134, R135, R136, R137, R148, R149, R150, R151, R152, R153, R164, R165, R166, R167, R168, R169, R180, R181, R182, R183, R184, R185: 100; 0402-TIGHT
R2, R3, R11, R12, R33, R34, R49, R50, R65, R66, R81, R82, R97, R98, R113, R114, R129, R130, R145, R146, R161, R162, R177, R178: 2.2k; 0402-TIGHT
R5, R19, R35, R51, R67, R83, R99, R115, R131, R147, R163, R179: 1k; 0402-TIGHT
R10, R13, R14, R15, R16, R17, R26, R27, R28, R29, R30, R32, R42, R43, R44, R45, R46, R48, R58, R59, R60, R61, R62, R64, R74, R75, R76, R77, R78, R80, R90, R91, R92, R93, R94, R96, R106, R107, R108, R109, R110, R112, R122, R123, R124, R125, R126, R128, R138, R139, R140, R141, R142, R144, R154, R155, R156, R157, R158, R160, R170, R171, R172, R173, R174, R176, R186, R187, R188, R189, R190, R192: 10Ω; 0402-TIGHT
R18, R31, R47, R63, R79, R95, R111, R127, R143, R159, R175, R191: 100k; 0402-TIGHT
SPKVDD, SPKVDD1, SPKVDD2, SPKVDD3, SPKVDD4, SPKVDD5, SPKVDD6, SPKVDD7, SPKVDD8, SPKVDD9, SPKVDD10, SPKVDD11: SMT-JUMPER_3_1-NC_TRACE_SILK
U1, U4, U5, U7, U9, U11, U13, U15, U17, U19, U21, U23: WM8960; QFN-32
U2, U3, U6, U8, U10, U12, U14, U16, U18, U20, U22, U24: XC6222B331MR-G; SOT23-5
U$1, U$109, U$186, U$263, U$340, U$417, U$494, U$571, U$648, U$725, U$802, U$879: AUDIO8960896055
U$2, U$110, U$187, U$264, U$341, U$418, U$495, U$572, U$649, U$726, U$803, U$880: CODEC8960896056
U$3, U$111, U$188, U$265, U$342, U$419, U$496, U$573, U$650, U$727, U$804, U$881: CODEC8960896057
U$4, U$7, U$8, U$9, U$11, U$12, U$17, U$18, U$19, U$31, U$32, U$43, U$50, U$93, U$113, U$114, U$115, U$117, U$118, U$119, U$120, U$121, U$123, U$124, U$159, U$170, U$190, U$191, U$192, U$194, U$195, U$196, U$197, U$198, U$200, U$201, U$236, U$247, U$267, U$268, U$269, U$271, U$272, U$273, U$274, U$275, U$277, U$278, U$313, U$324, U$344, U$345, U$346, U$348, U$349, U$350, U$351, U$352, U$354, U$355, U$390, U$401, U$421, U$422, U$423, U$425, U$426, U$427, U$428, U$429, U$431, U$432, U$467, U$478, U$498, U$499, U$500, U$502, U$503, U$504, U$505, U$506, U$508, U$509, U$544, U$555, U$575, U$576, U$577, U$579, U$580, U$581, U$582, U$583, U$585, U$586, U$621, U$632, U$652, U$653, U$654, U$656, U$657, U$658, U$659, U$660, U$662, U$663, U$698, U$709, U$729, U$730, U$731, U$733, U$734, U$735, U$736, U$737, U$739, U$740, U$775, U$786, U$806, U$807, U$808, U$810, U$811, U$812, U$813, U$814, U$816, U$817, U$852, U$863, U$883, U$884, U$885, U$887, U$888, U$889, U$890, U$891, U$893, U$894: #GND#8
U$5, U$145, U$222, U$299, U$376, U$453, U$530, U$607, U$684, U$761, U$838, U$915: #BCLK#0
U$6, U$13, U$155, U$232, U$309, U$386, U$463, U$540, U$617, U$694, U$771, U$848: #SR##4
U$10, U$48, U$92, U$116, U$169, U$193, U$246, U$270, U$323, U$347, U$400, U$424, U$477, U$501, U$554, U$578, U$631, U$655, U$708, U$732, U$785, U$809, U$862, U$886: #AVDD#22
U$14, U$33, U$157, U$234, U$311, U$388, U$465, U$542, U$619, U$696, U$773, U$850: #SL##6
U$15, U$25, U$156, U$233, U$310, U$387, U$464, U$541, U$618, U$695, U$772, U$849: #SR##5
U$16, U$42, U$158, U$235, U$312, U$389, U$466, U$543, U$620, U$697, U$774, U$851: #SL##7
U$20, U$134, U$211, U$288, U$365, U$442, U$519, U$596, U$673, U$750, U$827, U$904: #AVDD#ISO#0
U$21, U$135, U$212, U$289, U$366, U$443, U$520, U$597, U$674, U$751, U$828, U$905: #3V3#0
U$22, U$136, U$213, U$290, U$367, U$444, U$521, U$598, U$675, U$752, U$829, U$906: #VIN#0
U$23, U$146, U$223, U$300, U$377, U$454, U$531, U$608, U$685, U$762, U$839, U$916: #ALRC#0
U$24, U$147, U$224, U$301, U$378, U$455, U$532, U$609, U$686, U$763, U$840, U$917: #DLRC#1
U$26, U$53, U$160, U$237, U$314, U$391, U$468, U$545, U$622, U$699, U$776, U$853: #HPL#10
U$27, U$72, U$161, U$238, U$315, U$392, U$469, U$546, U$623, U$700, U$777, U$854: #HPR#11
U$28, U$51, U$73, U$94, U$162, U$171, U$239, U$248, U$316, U$325, U$393, U$402, U$470, U$479, U$547, U$556, U$624, U$633, U$701, U$710, U$778, U$787, U$855, U$864: #3V3#12
U$29, U$81, U$163, U$240, U$317, U$394, U$471, U$548, U$625, U$702, U$779, U$856: SFE_LOGO_FLAME_.1
U$30, U$64, U$107, U$122, U$184, U$199, U$261, U$276, U$338, U$353, U$415, U$430, U$492, U$507, U$569, U$584, U$646, U$661, U$723, U$738, U$800, U$815, U$877, U$892: #SPKVDD#51
U$34, U$125, U$202, U$279, U$356, U$433, U$510, U$587, U$664, U$741, U$818, U$895: ##EN##1
U$35, U$87, U$164, U$241, U$318, U$395, U$472, U$549, U$626, U$703, U$780, U$857: PWR12
U$36, U$108, U$185, U$262, U$339, U$416, U$493, U$570, U$647, U$724, U$801, U$878: WM8960896054
U$37, U$112, U$189, U$266, U$343, U$420, U$497, U$574, U$651, U$728, U$805, U$882: #OUT3#0
U$38, U$126, U$203, U$280, U$357, U$434, U$511, U$588, U$665, U$742, U$819, U$896: ##EN##2
U$39, U$88, U$165, U$242, U$319, U$396, U$473, U$550, U$627, U$704, U$781, U$858: #LED#17
U$40, U$89, U$166, U$243, U$320, U$397, U$474, U$551, U$628, U$705, U$782, U$859: #I2C#18
U$41, U$127, U$204, U$281, U$358, U$435, U$512, U$589, U$666, U$743, U$820, U$897: #OUT3#4
U$44, U$128, U$205, U$282, U$359, U$436, U$513, U$590, U$667, U$744, U$821, U$898: #RINPUT1#0
U$45, U$46, U$90, U$91, U$167, U$168, U$244, U$245, U$321, U$322, U$398, U$399, U$475, U$476, U$552, U$553, U$629, U$630, U$706, U$707, U$783, U$784, U$860, U$861: #VIN#19
U$47, U$129, U$206, U$283, U$360, U$437, U$514, U$591, U$668, U$745, U$822, U$899: #RINPUT2#0
U$49, U$130, U$207, U$284, U$361, U$438, U$515, U$592, U$669, U$746, U$823, U$900: #RINPUT3#0
U$52, U$148, U$225, U$302, U$379, U$456, U$533, U$610, U$687, U$764, U$841, U$918: #ADCLRC#2
U$54, U$139, U$216, U$293, U$370, U$447, U$524, U$601, U$678, U$755, U$832, U$909: #RIN3#0
U$55, U$149, U$226, U$303, U$380, U$457, U$534, U$611, U$688, U$765, U$842, U$919: #DACLRC#4
U$56, U$140, U$217, U$294, U$371, U$448, U$525, U$602, U$679, U$756, U$833, U$910: #RIN2#0
U$57, U$150, U$227, U$304, U$381, U$458, U$535, U$612, U$689, U$766, U$843, U$920: #BCLK#5
U$58, U$151, U$228, U$305, U$382, U$459, U$536, U$613, U$690, U$767, U$844, U$921: #ADCDAT#6
U$59, U$95, U$172, U$249, U$326, U$403, U$480, U$557, U$634, U$711, U$788, U$865: #MICB#31
U$60, U$96, U$173, U$250, U$327, U$404, U$481, U$558, U$635, U$712, U$789, U$866: WM89600
U$61, U$97, U$174, U$251, U$328, U$405, U$482, U$559, U$636, U$713, U$790, U$867: AUDIO0
U$62, U$131, U$208, U$285, U$362, U$439, U$516, U$593, U$670, U$747, U$824, U$901: #LINPUT1#0
U$63, U$132, U$209, U$286, U$363, U$440, U$517, U$594, U$671, U$748, U$825, U$902: #LINPUT2#0
U$65, U$133, U$210, U$287, U$364, U$441, U$518, U$595, U$672, U$749, U$826, U$903: #LINPUT3#0
U$66, U$137, U$214, U$291, U$368, U$445, U$522, U$599, U$676, U$753, U$830, U$907: #SCL#0
U$67, U$138, U$215, U$292, U$369, U$446, U$523, U$600, U$677, U$754, U$831, U$908: #SDA#0
U$68, U$141, U$218, U$295, U$372, U$449, U$526, U$603, U$680, U$757, U$834, U$911: #RIN1#0
U$69, U$153, U$230, U$307, U$384, U$461, U$538, U$615, U$692, U$769, U$846, U$923: #DDAT#9
U$70, U$152, U$229, U$306, U$383, U$460, U$537, U$614, U$691, U$768, U$845, U$922: #DACDAT#8
U$71, U$154, U$231, U$308, U$385, U$462, U$539, U$616, U$693, U$770, U$847, U$924: #ADAT#10
U$74, U$98, U$175, U$252, U$329, U$406, U$483, U$560, U$637, U$714, U$791, U$868: #SCL#40
U$75, U$99, U$176, U$253, U$330, U$407, U$484, U$561, U$638, U$715, U$792, U$869: #SDA#41
U$76, U$142, U$219, U$296, U$373, U$450, U$527, U$604, U$681, U$758, U$835, U$912: #LIN1#0
U$77, U$143, U$220, U$297, U$374, U$451, U$528, U$605, U$682, U$759, U$836, U$913: #LIN2#0
U$78, U$144, U$221, U$298, U$375, U$452, U$529, U$606, U$683, U$760, U$837, U$914: #LIN3#0
U$79, U$100, U$177, U$254, U$331, U$408, U$485, U$562, U$639, U$716, U$793, U$870: #MICBIAS#42
U$80, U$101, U$178, U$255, U$332, U$409, U$486, U$563, U$640, U$717, U$794, U$871: #HPL#43
U$82, U$102, U$179, U$256, U$333, U$410, U$487, U$564, U$641, U$718, U$795, U$872: #HPR#45
U$83, U$103, U$180, U$257, U$334, U$411, U$488, U$565, U$642, U$719, U$796, U$873: #SPK_LP#46
U$84, U$104, U$181, U$258, U$335, U$412, U$489, U$566, U$643, U$720, U$797, U$874: #SPK_LN#47
U$85, U$105, U$182, U$259, U$336, U$413, U$490, U$567, U$644, U$721, U$798, U$875: #SPK_RP#48
U$86, U$106, U$183, U$260, U$337, U$414, U$491, U$568, U$645, U$722, U$799, U$876: #SPK_RN#49
Y1, Y2, Y3, Y4, Y5, Y6, Y7, Y8, Y9, Y10, Y11, Y12: 24 MHz; RESONATOR-SMD-3.2X2.5

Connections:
3.3V: C3.2, C4.2, C5.2, C13.1, I2C.2, J1.2, J4.8, LED.2, SPKVDD.1, U4.8, U4.10, Y1.1, Y1.4
3.3V1: C2.2, C11.2, C32.2, C35.1, I2C1.2, J2.2, J3.8, LED1.2, SPKVDD1.1, U1.8, U1.10, Y2.1, Y2.4
3.3V2: C59.2, C60.2, C61.2, C64.1, I2C2.2, J7.2, J8.8, LED2.2, SPKVDD2.1, U5.8, U5.10, Y3.1, Y3.4
3.3V3: C88.2, C89.2, C90.2, C93.1, I2C3.2, J10.2, J11.8, LED3.2, SPKVDD3.1, U7.8, U7.10, Y4.1, Y4.4
3.3V4: C117.2, C118.2, C119.2, C122.1, I2C4.2, J13.2, J14.8, LED4.2, SPKVDD4.1, U9.8, U9.10, Y5.1, Y5.4
3.3V5: C146.2, C147.2, C148.2, C151.1, I2C5.2, J16.2, J17.8, LED5.2, SPKVDD5.1, U11.8, U11.10, Y6.1, Y6.4
3.3V6: C175.2, C176.2, C177.2, C180.1, I2C6.2, J19.2, J20.8, LED6.2, SPKVDD6.1, U13.8, U13.10, Y7.1, Y7.4
3.3V7: C204.2, C205.2, C206.2, C209.1, I2C7.2, J22.2, J23.8, LED7.2, SPKVDD7.1, U15.8, U15.10, Y8.1, Y8.4
3.3V8: C233.2, C234.2, C235.2, C238.1, I2C8.2, J25.2, J26.8, LED8.2, SPKVDD8.1, U17.8, U17.10, Y9.1, Y9.4
3.3V9: C262.2, C263.2, C264.2, C267.1, I2C9.2, J28.2, J29.8, LED9.2, SPKVDD9.1, U19.8, U19.10, Y10.1, Y10.4
3.3V10: C291.2, C292.2, C293.2, C296.1, I2C10.2, J31.2, J32.8, LED10.2, SPKVDD10.1, U21.8, U21.10, Y11.1, Y11.4
3.3V11: C320.2, C321.2, C322.2, C325.1, I2C11.2, J34.2, J35.8, LED11.2, SPKVDD11.1, U23.8, U23.10, Y12.1, Y12.4
ADCDAT: J4.11, R16.1
ADCDAT1: J3.11, R29.1
ADCDAT2: J8.11, R45.1
ADCDAT3: J11.11, R61.1
ADCDAT4: J14.11, R77.1
ADCDAT5: J17.11, R93.1
ADCDAT6: J20.11, R109.1
ADCDAT7: J23.11, R125.1
ADCDAT8: J26.11, R141.1
ADCDAT9: J29.11, R157.1
ADCDAT10: J32.11, R173.1
ADCDAT11: J35.11, R189.1
ADCLRC: J4.12, R13.1
ADCLRC1: J3.12, R26.1
ADCLRC2: J8.12, R42.1
ADCLRC3: J11.12, R58.1
ADCLRC4: J14.12, R74.1
ADCLRC5: J17.12, R90.1
ADCLRC6: J20.12, R106.1
ADCLRC7: J23.12, R122.1
ADCLRC8: J26.12, R138.1
ADCLRC9: J29.12, R154.1
ADCLRC10: J32.12, R170.1
ADCLRC11: J35.12, R186.1
AVDD: AVDD-ISO.2, C10.2, J5.5, U4.32
AVDD1: AVDD-ISO1.2, C53.2, J6.5, U1.32
AVDD2: AVDD-ISO2.2, C82.2, J9.5, U5.32
AVDD3: AVDD-ISO3.2, C111.2, J12.5, U7.32
AVDD4: AVDD-ISO4.2, C140.2, J15.5, U9.32
AVDD5: AVDD-ISO5.2, C169.2, J18.5, U11.32
AVDD6: AVDD-ISO6.2, C198.2, J21.5, U13.32
AVDD7: AVDD-ISO7.2, C227.2, J24.5, U15.32
AVDD8: AVDD-ISO8.2, C256.2, J27.5, U17.32
AVDD9: AVDD-ISO9.2, C285.2, J30.5, U19.32
AVDD10: AVDD-ISO10.2, C314.2, J33.5, U21.32
AVDD11: AVDD-ISO11.2, C343.2, J36.5, U23.32
AVDD-REG: AVDD-ISO.1, C12.1, C14.1, U3.5
AVDD-REG1: AVDD-ISO1.1, C56.1, C57.1, U2.5
AVDD-REG2: AVDD-ISO2.1, C85.1, C86.1, U6.5
AVDD-REG3: AVDD-ISO3.1, C114.1, C115.1, U8.5
AVDD-REG4: AVDD-ISO4.1, C143.1, C144.1, U10.5
AVDD-REG5: AVDD-ISO5.1, C172.1, C173.1, U12.5
AVDD-REG6: AVDD-ISO6.1, C201.1, C202.1, U14.5
AVDD-REG7: AVDD-ISO7.1, C230.1, C231.1, U16.5
AVDD-REG8: AVDD-ISO8.1, C259.1, C260.1, U18.5
AVDD-REG9: AVDD-ISO9.1, C288.1, C289.1, U20.5
AVDD-REG10: AVDD-ISO10.1, C317.1, C318.1, U22.5
AVDD-REG11: AVDD-ISO11.1, C346.1, C347.1, U24.5
BCLK: J4.15, R15.1
BCLK1: J3.15, R28.1
BCLK2: J8.15, R44.1
BCLK3: J11.15, R60.1
BCLK4: J14.15, R76.1
BCLK5: J17.15, R92.1
BCLK6: J20.15, R108.1
BCLK7: J23.15, R124.1
BCLK8: J26.15, R140.1
BCLK9: J29.15, R156.1
BCLK10: J32.15, R172.1
BCLK11: J35.15, R188.1
DACDAT: J4.13, R17.1
DACDAT1: J3.13, R30.1
DACDAT2: J8.13, R46.1
DACDAT3: J11.13, R62.1
DACDAT4: J14.13, R78.1
DACDAT5: J17.13, R94.1
DACDAT6: J20.13, R110.1
DACDAT7: J23.13, R126.1
DACDAT8: J26.13, R142.1
DACDAT9: J29.13, R158.1
DACDAT10: J32.13, R174.1
DACDAT11: J35.13, R190.1
DACLRC: J4.14, R14.1
DACLRC1: J3.14, R27.1
DACLRC2: J8.14, R43.1
DACLRC3: J11.14, R59.1
DACLRC4: J14.14, R75.1
DACLRC5: J17.14, R91.1
DACLRC6: J20.14, R107.1
DACLRC7: J23.14, R123.1
DACLRC8: J26.14, R139.1
DACLRC9: J29.14, R155.1
DACLRC10: J32.14, R171.1
DACLRC11: J35.14, R187.1
EN: J4.3, R18.2, U3.3
EN1: J3.3, R31.2, U2.3
EN2: J8.3, R47.2, U6.3
EN3: J11.3, R63.2, U8.3
EN4: J14.3, R79.2, U10.3
EN5: J17.3, R95.2, U12.3
EN6: J20.3, R111.2, U14.3
EN7: J23.3, R127.2, U16.3
EN8: J26.3, R143.2, U18.3
EN9: J29.3, R159.2, U20.3
EN10: J32.3, R175.2, U22.3
EN11: J35.3, R191.2, U24.3
GND: C1.2, C3.1, C4.1, C5.1, C6.2, C7.2, C8.1, C9.1, C10.1, C12.2, C13.2, C14.2, C15.2, C16.2, C17.2, C18.2, C21.2, C22.2, C27.2, C28.2, C29.2, C30.2, C31.2, J1.1, J4.1, J4.2, J4.6, J4.7, J4.16, J5.16, R5.1, U3.2, U4.9, U4.20, U4.24, U4.28, U4.PADDLE, Y1.2
GND1: C2.1, C11.1, C32.1, C33.1, C34.1, C35.2, C36.2, C37.2, C38.2, C39.2, C42.2, C43.2, C48.2, C49.2, C50.2, C51.2, C52.2, C53.1, C54.2, C55.2, C56.2, C57.2, C58.2, J2.1, J3.1, J3.2, J3.6, J3.7, J3.16, J6.16, R19.1, U1.9, U1.20, U1.24, U1.28, U1.PADDLE, U2.2, Y2.2
GND2: C59.1, C60.1, C61.1, C62.1, C63.1, C64.2, C65.2, C66.2, C67.2, C68.2, C71.2, C72.2, C77.2, C78.2, C79.2, C80.2, C81.2, C82.1, C83.2, C84.2, C85.2, C86.2, C87.2, J7.1, J8.1, J8.2, J8.6, J8.7, J8.16, J9.16, R35.1, U5.9, U5.20, U5.24, U5.28, U5.PADDLE, U6.2, Y3.2
GND3: C88.1, C89.1, C90.1, C91.1, C92.1, C93.2, C94.2, C95.2, C96.2, C97.2, C100.2, C101.2, C106.2, C107.2, C108.2, C109.2, C110.2, C111.1, C112.2, C113.2, C114.2, C115.2, C116.2, J10.1, J11.1, J11.2, J11.6, J11.7, J11.16, J12.16, R51.1, U7.9, U7.20, U7.24, U7.28, U7.PADDLE, U8.2, Y4.2
GND4: C117.1, C118.1, C119.1, C120.1, C121.1, C122.2, C123.2, C124.2, C125.2, C126.2, C129.2, C130.2, C135.2, C136.2, C137.2, C138.2, C139.2, C140.1, C141.2, C142.2, C143.2, C144.2, C145.2, J13.1, J14.1, J14.2, J14.6, J14.7, J14.16, J15.16, R67.1, U9.9, U9.20, U9.24, U9.28, U9.PADDLE, U10.2, Y5.2
GND5: C146.1, C147.1, C148.1, C149.1, C150.1, C151.2, C152.2, C153.2, C154.2, C155.2, C158.2, C159.2, C164.2, C165.2, C166.2, C167.2, C168.2, C169.1, C170.2, C171.2, C172.2, C173.2, C174.2, J16.1, J17.1, J17.2, J17.6, J17.7, J17.16, J18.16, R83.1, U11.9, U11.20, U11.24, U11.28, U11.PADDLE, U12.2, Y6.2
GND6: C175.1, C176.1, C177.1, C178.1, C179.1, C180.2, C181.2, C182.2, C183.2, C184.2, C187.2, C188.2, C193.2, C194.2, C195.2, C196.2, C197.2, C198.1, C199.2, C200.2, C201.2, C202.2, C203.2, J19.1, J20.1, J20.2, J20.6, J20.7, J20.16, J21.16, R99.1, U13.9, U13.20, U13.24, U13.28, U13.PADDLE, U14.2, Y7.2
GND7: C204.1, C205.1, C206.1, C207.1, C208.1, C209.2, C210.2, C211.2, C212.2, C213.2, C216.2, C217.2, C222.2, C223.2, C224.2, C225.2, C226.2, C227.1, C228.2, C229.2, C230.2, C231.2, C232.2, J22.1, J23.1, J23.2, J23.6, J23.7, J23.16, J24.16, R115.1, U15.9, U15.20, U15.24, U15.28, U15.PADDLE, U16.2, Y8.2
GND8: C233.1, C234.1, C235.1, C236.1, C237.1, C238.2, C239.2, C240.2, C241.2, C242.2, C245.2, C246.2, C251.2, C252.2, C253.2, C254.2, C255.2, C256.1, C257.2, C258.2, C259.2, C260.2, C261.2, J25.1, J26.1, J26.2, J26.6, J26.7, J26.16, J27.16, R131.1, U17.9, U17.20, U17.24, U17.28, U17.PADDLE, U18.2, Y9.2
GND9: C262.1, C263.1, C264.1, C265.1, C266.1, C267.2, C268.2, C269.2, C270.2, C271.2, C274.2, C275.2, C280.2, C281.2, C282.2, C283.2, C284.2, C285.1, C286.2, C287.2, C288.2, C289.2, C290.2, J28.1, J29.1, J29.2, J29.6, J29.7, J29.16, J30.16, R147.1, U19.9, U19.20, U19.24, U19.28, U19.PADDLE, U20.2, Y10.2
GND10: C291.1, C292.1, C293.1, C294.1, C295.1, C296.2, C297.2, C298.2, C299.2, C300.2, C303.2, C304.2, C309.2, C310.2, C311.2, C312.2, C313.2, C314.1, C315.2, C316.2, C317.2, C318.2, C319.2, J31.1, J32.1, J32.2, J32.6, J32.7, J32.16, J33.16, R163.1, U21.9, U21.20, U21.24, U21.28, U21.PADDLE, U22.2, Y11.2
GND11: C320.1, C321.1, C322.1, C323.1, C324.1, C325.2, C326.2, C327.2, C328.2, C329.2, C332.2, C333.2, C338.2, C339.2, C340.2, C341.2, C342.2, C343.1, C344.2, C345.2, C346.2, C347.2, C348.2, J34.1, J35.1, J35.2, J35.6, J35.7, J35.16, J36.16, R179.1, U23.9, U23.20, U23.24, U23.28, U23.PADDLE, U24.2, Y12.2
HP_L: J5.8, U4.31
HP_L1: J6.8, U1.31
HP_L2: J9.8, U5.31
HP_L3: J12.8, U7.31
HP_L4: J15.8, U9.31
HP_L5: J18.8, U11.31
HP_L6: J21.8, U13.31
HP_L7: J24.8, U15.31
HP_L8: J27.8, U17.31
HP_L9: J30.8, U19.31
HP_L10: J33.8, U21.31
HP_L11: J36.8, U23.31
HP_R: J5.6, U4.29
HP_R1: J6.6, U1.29
HP_R2: J9.6, U5.29
HP_R3: J12.6, U7.29
HP_R4: J15.6, U9.29
HP_R5: J18.6, U11.29
HP_R6: J21.6, U13.29
HP_R7: J24.6, U15.29
HP_R8: J27.6, U17.29
HP_R9: J30.6, U19.29
HP_R10: J33.6, U21.29
HP_R11: J36.6, U23.29
LINPUT1: J5.12, R4.1
LINPUT2: J5.11, R6.1
LINPUT3: J5.10, R1.1
LINPUT4: J6.12, R20.1
LINPUT5: J6.10, R22.1
LINPUT6: J6.11, R21.1
LINPUT7: J9.12, R36.1
LINPUT8: J9.10, R38.1
LINPUT9: J9.11, R37.1
LINPUT10: J12.12, R52.1
LINPUT11: J12.10, R54.1
LINPUT12: J12.11, R53.1
LINPUT13: J15.12, R68.1
LINPUT14: J15.10, R70.1
LINPUT15: J15.11, R69.1
LINPUT16: J18.12, R84.1
LINPUT17: J18.10, R86.1
LINPUT18: J18.11, R85.1
LINPUT19: J21.12, R100.1
LINPUT20: J21.10, R102.1
LINPUT21: J21.11, R101.1
LINPUT22: J24.12, R116.1
LINPUT23: J24.10, R118.1
LINPUT24: J24.11, R117.1
LINPUT25: J27.12, R132.1
LINPUT26: J27.10, R134.1
LINPUT27: J27.11, R133.1
LINPUT28: J30.12, R148.1
LINPUT29: J30.10, R150.1
LINPUT30: J30.11, R149.1
LINPUT31: J33.12, R164.1
LINPUT32: J33.10, R166.1
LINPUT33: J33.11, R165.1
LINPUT34: J36.12, R180.1
LINPUT35: J36.10, R182.1
LINPUT36: J36.11, R181.1
MICBIAS: C9.2, J5.9, U4.1
MICBIAS1: C34.2, J6.9, U1.1
MICBIAS2: C63.2, J9.9, U5.1
MICBIAS3: C92.2, J12.9, U7.1
MICBIAS4: C121.2, J15.9, U9.1
MICBIAS5: C150.2, J18.9, U11.1
MICBIAS6: C179.2, J21.9, U13.1
MICBIAS7: C208.2, J24.9, U15.1
MICBIAS8: C237.2, J27.9, U17.1
MICBIAS9: C266.2, J30.9, U19.1
MICBIAS10: C295.2, J33.9, U21.1
MICBIAS11: C324.2, J36.9, U23.1
unnamed: L3.1, U4.22
unnamed: R13.2, U4.15
unnamed: L4.1, U4.19
unnamed: L2.1, U4.25
unnamed: L1.1, U4.23
unnamed: D1.C, R5.2
unnamed: D1.A, LED.1
unnamed: C26.2, U4.7
unnamed: C25.2, U4.6
unnamed: C23.2, U4.2
unnamed: R10.1, Y1.3
unnamed: C20.2, U4.3
unnamed: C20.1, C21.1, R6.2
unnamed: C19.1, C22.1, R4.2
unnamed: C23.1, C27.1, R1.2
unnamed: I2C.3, R2.2
unnamed: I2C.1, R3.2
unnamed: C24.1, C28.1, R7.2
unnamed: C25.1, C29.1, R8.2
unnamed: C26.1, C30.1, R9.2
unnamed: R14.2, U4.13
unnamed: R15.2, U4.12
unnamed: R16.2, U4.16
unnamed: R17.2, U4.14
unnamed: R10.2, U4.11
unnamed: C40.2, U1.4
unnamed: C45.2, U1.5
unnamed: C33.2, U1.27
unnamed: C19.2, U4.4
unnamed: C24.2, U4.5
unnamed: I2C1.3, R11.2
unnamed: I2C1.1, R12.2
unnamed: R32.1, Y2.3
unnamed: C47.2, U1.7
unnamed: C46.2, U1.6
unnamed: C44.2, U1.2
unnamed: C41.2, U1.3
unnamed: C8.2, U4.27
unnamed: L7.1, U1.22
unnamed: L8.1, U1.19
unnamed: L6.1, U1.25
unnamed: L5.1, U1.23
unnamed: D2.C, R19.2
unnamed: C41.1, C42.1, R21.2
unnamed: C40.1, C43.1, R20.2
unnamed: C44.1, C48.1, R22.2
unnamed: C45.1, C49.1, R23.2
unnamed: C46.1, C50.1, R24.2
unnamed: C47.1, C51.1, R25.2
unnamed: R26.2, U1.15
unnamed: R27.2, U1.13
unnamed: R28.2, U1.12
unnamed: R29.2, U1.16
unnamed: R30.2, U1.14
unnamed: R32.2, U1.11
unnamed: D2.A, LED1.1
unnamed: C69.2, U5.4
unnamed: C74.2, U5.5
unnamed: C62.2, U5.27
unnamed: I2C2.3, R33.2
unnamed: I2C2.1, R34.2
unnamed: R48.1, Y3.3
unnamed: C76.2, U5.7
unnamed: C75.2, U5.6
unnamed: C73.2, U5.2
unnamed: C70.2, U5.3
unnamed: L11.1, U5.22
unnamed: L12.1, U5.19
unnamed: L10.1, U5.25
unnamed: L9.1, U5.23
unnamed: D3.C, R35.2
unnamed: C70.1, C71.1, R37.2
unnamed: C69.1, C72.1, R36.2
unnamed: C73.1, C77.1, R38.2
unnamed: C74.1, C78.1, R39.2
unnamed: C75.1, C79.1, R40.2
unnamed: C76.1, C80.1, R41.2
unnamed: R42.2, U5.15
unnamed: R43.2, U5.13
unnamed: R44.2, U5.12
unnamed: R45.2, U5.16
unnamed: R46.2, U5.14
unnamed: R48.2, U5.11
unnamed: D3.A, LED2.1
unnamed: C98.2, U7.4
unnamed: C103.2, U7.5
unnamed: C91.2, U7.27
unnamed: I2C3.3, R49.2
unnamed: I2C3.1, R50.2
unnamed: R64.1, Y4.3
unnamed: C105.2, U7.7
unnamed: C104.2, U7.6
unnamed: C102.2, U7.2
unnamed: C99.2, U7.3
unnamed: L15.1, U7.22
unnamed: L16.1, U7.19
unnamed: L14.1, U7.25
unnamed: L13.1, U7.23
unnamed: D4.C, R51.2
unnamed: C99.1, C100.1, R53.2
unnamed: C98.1, C101.1, R52.2
unnamed: C102.1, C106.1, R54.2
unnamed: C103.1, C107.1, R55.2
unnamed: C104.1, C108.1, R56.2
unnamed: C105.1, C109.1, R57.2
unnamed: R58.2, U7.15
unnamed: R59.2, U7.13
unnamed: R60.2, U7.12
unnamed: R61.2, U7.16
unnamed: R62.2, U7.14
unnamed: R64.2, U7.11
unnamed: D4.A, LED3.1
unnamed: C127.2, U9.4
unnamed: C132.2, U9.5
unnamed: C120.2, U9.27
unnamed: I2C4.3, R65.2
unnamed: I2C4.1, R66.2
unnamed: R80.1, Y5.3
unnamed: C134.2, U9.7
unnamed: C133.2, U9.6
unnamed: C131.2, U9.2
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

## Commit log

2022-08-05 initial layout idea
    [Stereo_Audio_Codec_Breakout_WM8960.brd, Stereo_Audio_Codec_Breakout_WM8960.sch]
2022-10-06 Breakout routed ready for proto review
    [Stereo_Audio_Codec_Breakout_WM8960.brd, Stereo_Audio_Codec_Breakout_WM8960.sch]
2022-10-06 vector font
    [Stereo_Audio_Codec_Breakout_WM8960.sch]
2022-10-06 moved pwr led into sch frame
    [Stereo_Audio_Codec_Breakout_WM8960.sch]
2022-10-06 Switched MONO OUT to OUT3, because that is a better name
    [Stereo_Audio_Codec_Breakout_WM8960.brd, Stereo_Audio_Codec_Breakout_WM8960.sch]
2022-10-06 added measures
    [Stereo_Audio_Codec_Breakout_WM8960.brd]
2022-10-12 Switched to single GND plane
    -moved to smaller vreg for AVDD
    -changed how power jumpers selection and isolation works
    -created 3.3V and AVDD polygons on inner layers
    -increased header length to allow for 100% analog pins to be on same side.
    -split SPKVDD decoupling cap into two separate 4.7uF caps and put near IC pins
    -added 10 ohm in series resistors on all data lines.
    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
    [Stereo_Audio_Codec_Breakout_WM8960.brd, Stereo_Audio_Codec_Breakout_WM8960.sch]
2022-10-12 Removed top layer GND pour
    routed GND connections to Vias
    [Stereo_Audio_Codec_Breakout_WM8960.brd]
2022-10-13 checklist catches - eng run
    -Connected header pin (J4/7) to GND
    -Added 4-layer board 1/2/3/4 in copper
    -added ordering instructions
    -added Selective solder path and moved some resistors to provide clearance on medium nozzle
    -nudges some Vias to avoid cutting into silk
    [Stereo_Audio_Codec_Breakout_WM8960.brd, Stereo_Audio_Codec_Breakout_WM8960.sch]
2022-10-13 corrected typo in sch note about I2C pullup jumper
    [Stereo_Audio_Codec_Breakout_WM8960.sch]
2022-10-13 Proto Panel v01a
    [Stereo_Audio_Codec_Breakout_WM8960-Panel.GBL, Stereo_Audio_Codec_Breakout_WM8960-Panel.GBO, Stereo_Audio_Codec_Breakout_WM8960-Panel.GBP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]
2022-11-18 Silk updates and codec package update
    -corrected the I2S pins to be rounded flags (because they can be inputs or outputs)
    -extended pads on codec FP to allow for better fillets. (also increased roundness of pads)
    -corrected I2C address in schematic to 0x1A
    -bumped version to v10
    [Stereo_Audio_Codec_Breakout_WM8960.brd, Stereo_Audio_Codec_Breakout_WM8960.sch]
2022-11-18 replaced C6 and C7 to use proper SFE libraries
    -Also updated tCream on codec footprint
    [Stereo_Audio_Codec_Breakout_WM8960.brd, Stereo_Audio_Codec_Breakout_WM8960.sch]
2022-11-18 Corrected ADCDAT and DACDAT flag ends
    ADCDAT will always be an output from the ADC.
    DACDAT will always be an input - sent from the microcontroller that is sending SD to the DAC.
    [Stereo_Audio_Codec_Breakout_WM8960.brd]
2022-11-21 removing one wire stub on 3.3V off of qwiic connector
    [Stereo_Audio_Codec_Breakout_WM8960.brd]
2022-11-22 Moved fiducials to avoid silk overlap
    -also increase I2C address text size in sch
    [Stereo_Audio_Codec_Breakout_WM8960.brd, Stereo_Audio_Codec_Breakout_WM8960.sch]
2022-11-22 Production panel v10c
    [Stereo_Audio_Codec_Breakout_WM8960-Panel.GBL, Stereo_Audio_Codec_Breakout_WM8960-Panel.GBO, Stereo_Audio_Codec_Breakout_WM8960-Panel.GBP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]
2022-12-16 wm8960 breakout board file
    This is the full design "board" device/symbol/fp, for use as a drop into other bigger designs.
    -pretty much there, but still needs silk

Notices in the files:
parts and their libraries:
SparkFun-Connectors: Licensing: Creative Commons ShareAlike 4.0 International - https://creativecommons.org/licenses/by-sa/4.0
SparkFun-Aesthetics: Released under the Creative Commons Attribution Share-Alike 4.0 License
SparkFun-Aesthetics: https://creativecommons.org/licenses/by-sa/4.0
